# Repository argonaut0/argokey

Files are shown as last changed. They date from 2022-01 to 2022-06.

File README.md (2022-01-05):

# Unnamed Keyboard Project

A Custom 65% Mechanical Keyboard with RGB lighting, an OLED status screen, and volume knob.

Possibly with the first ever keyboard firmware fulling supporting multithreading?

### References

- https://datasheets.raspberrypi.com/rp2040/rp2040-datasheet.pdf
- https://datasheets.raspberrypi.com/rp2040/hardware-design-with-rp2040.pdf

### Symbols and Models
- https://github.com/daprice/keyswitches.pretty
- https://app.ultralibrarian.com/details/718f6c74-6ffb-11eb-9033-0a34d6323d74/Raspberry-Pi/RP2040
- https://app.ultralibrarian.com/details/76A34700-1D87-11E9-AB3A-0A3560A4CCCC/Winbond/W25Q64JVSSIQ

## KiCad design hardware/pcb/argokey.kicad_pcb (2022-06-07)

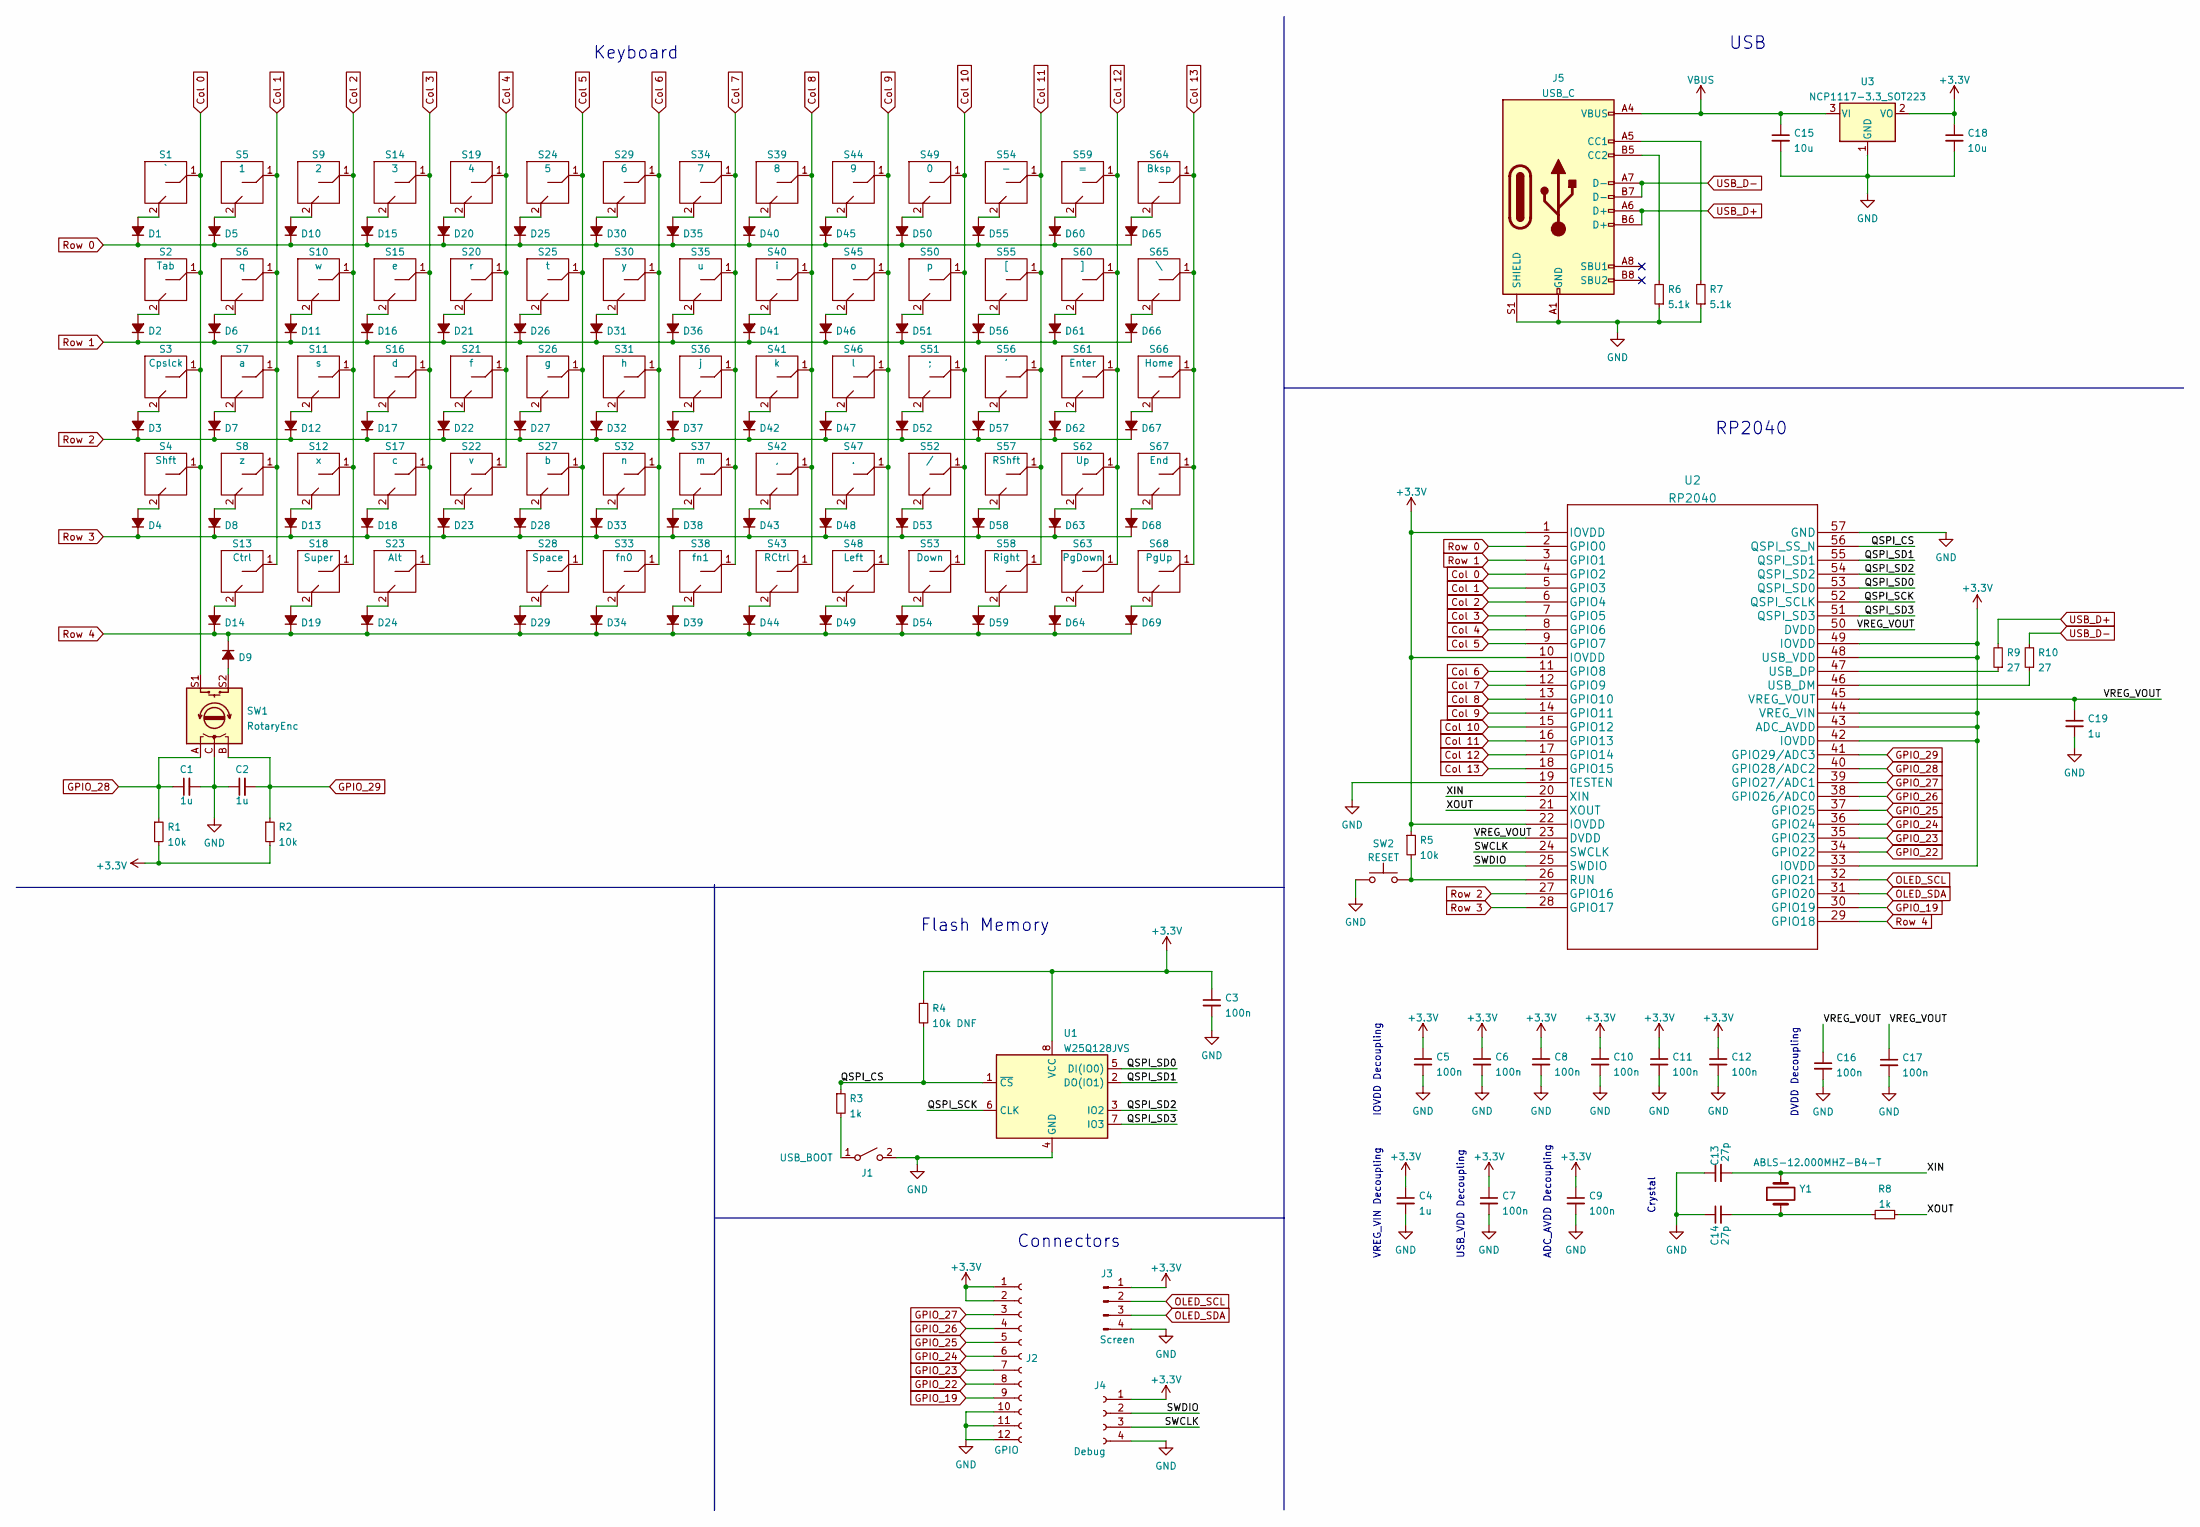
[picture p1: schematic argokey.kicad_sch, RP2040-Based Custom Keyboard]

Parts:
C1, C2, C4, C19: 1u; C_0402_1005Metric_Pad0.74x0.62mm_HandSolder
C3, C5, C6, C7, C8, C9, C10, C11, C12, C16, C17: 100n; C_0402_1005Metric_Pad0.74x0.62mm_HandSolder
C13, C14: 27p; C_0402_1005Metric_Pad0.74x0.62mm_HandSolder
C15, C18: 10u; C_0805_2012Metric_Pad1.18x1.45mm_HandSolder
D1, D2, D3, D4, D5, D6, D7, D8, D9, D10, D11, D12, D13, D14, D15, D16, D18, D19, D20, D21, D22, D23, D24, D25, D26, D27, D28, D29, D30, D31, D32, D33, D34, D35, D36, D37, D38, D39, D40, D41, D42, D43, D44, D45, D46, D47, D48, D49, D50, D51, D52, D53, D54, D55, D56, D57, D58, D59, D60, D61, D62, D63, D64, D65, D66, D67, D68, D69: D_SOD-123
D17: D_SOD-123
J1: USB_BOOT; SW_SPDT_PCM12
J2: GPIO; PinSocket_1x12_P2.54mm_Horizontal
J3: Screen; PinHeader_1x04_P2.54mm_Vertical
J4: Debug; PinSocket_1x04_P2.54mm_Horizontal
J5: USB_C; USB_C_Receptacle_GCT_USB4085
R1, R2, R5: 10k; R_0402_1005Metric_Pad0.72x0.64mm_HandSolder
R3, R8: 1k; R_0402_1005Metric_Pad0.72x0.64mm_HandSolder
R4: 10k DNF; R_0402_1005Metric_Pad0.72x0.64mm_HandSolder
R6, R7: 5.1k; R_0402_1005Metric_Pad0.72x0.64mm_HandSolder
R9, R10: 27; R_0402_1005Metric_Pad0.72x0.64mm_HandSolder
S1: `; SW_Cherry_MX_1.00u_PCB
S2: Tab; SW_Cherry_MX_1.50u_PCB
S3: Cpslck; SW_Cherry_MX_1.75u_PCB
S4: Shft; SW_Cherry_MX_2.25u_PCB
S5: 1; SW_Cherry_MX_1.00u_PCB
S6: q; SW_Cherry_MX_1.00u_PCB
S7: a; SW_Cherry_MX_1.00u_PCB
S8: z; SW_Cherry_MX_1.00u_PCB
S9: 2; SW_Cherry_MX_1.00u_PCB
S10: w; SW_Cherry_MX_1.00u_PCB
S11: s; SW_Cherry_MX_1.00u_PCB
S12: x; SW_Cherry_MX_1.00u_PCB
S13: Ctrl; SW_Cherry_MX_1.25u_PCB
S14: 3; SW_Cherry_MX_1.00u_PCB
S15: e; SW_Cherry_MX_1.00u_PCB
S16: d; SW_Cherry_MX_1.00u_PCB
S17: c; SW_Cherry_MX_1.00u_PCB
S18: Super; SW_Cherry_MX_1.25u_PCB
S19: 4; SW_Cherry_MX_1.00u_PCB
S20: r; SW_Cherry_MX_1.00u_PCB
S21: f; SW_Cherry_MX_1.00u_PCB
S22: v; SW_Cherry_MX_1.00u_PCB
S23: Alt; SW_Cherry_MX_1.25u_PCB
S24: 5; SW_Cherry_MX_1.00u_PCB
S25: t; SW_Cherry_MX_1.00u_PCB
S26: g; SW_Cherry_MX_1.00u_PCB
S27: b; SW_Cherry_MX_1.00u_PCB
S28: Space; SW_Cherry_MX_6.25u_PCB
S29: 6; SW_Cherry_MX_1.00u_PCB
S30: y; SW_Cherry_MX_1.00u_PCB
S31: h; SW_Cherry_MX_1.00u_PCB
S32: n; SW_Cherry_MX_1.00u_PCB
S33: fn0; SW_Cherry_MX_1.00u_PCB
S34: 7; SW_Cherry_MX_1.00u_PCB
S35: u; SW_Cherry_MX_1.00u_PCB
S36: j; SW_Cherry_MX_1.00u_PCB
S37: m; SW_Cherry_MX_1.00u_PCB
S38: fn1; SW_Cherry_MX_1.00u_PCB
S39: 8; SW_Cherry_MX_1.00u_PCB
S40: i; SW_Cherry_MX_1.00u_PCB
S41: k; SW_Cherry_MX_1.00u_PCB
S42: ,; SW_Cherry_MX_1.00u_PCB
S43: RCtrl; SW_Cherry_MX_1.00u_PCB
S44: 9; SW_Cherry_MX_1.00u_PCB
S45: o; SW_Cherry_MX_1.00u_PCB
S46: l; SW_Cherry_MX_1.00u_PCB
S47: .; SW_Cherry_MX_1.00u_PCB
S48: Left; SW_Cherry_MX_1.00u_PCB
S49: 0; SW_Cherry_MX_1.00u_PCB
S50: p; SW_Cherry_MX_1.00u_PCB
S51: ;; SW_Cherry_MX_1.00u_PCB
S52: /; SW_Cherry_MX_1.00u_PCB
S53: Down; SW_Cherry_MX_1.00u_PCB
S54: -; SW_Cherry_MX_1.00u_PCB
S55: [; SW_Cherry_MX_1.00u_PCB
S56: '; SW_Cherry_MX_1.00u_PCB
S57: RShft; SW_Cherry_MX_1.75u_PCB
S58: Right; SW_Cherry_MX_1.00u_PCB
S59: =; SW_Cherry_MX_1.00u_PCB
S60: ]; SW_Cherry_MX_1.00u_PCB
S61: Enter; SW_Cherry_MX_2.25u_PCB
S62: Up; SW_Cherry_MX_1.00u_PCB
S63: PgDown; SW_Cherry_MX_1.00u_PCB
S64: Bksp; SW_Cherry_MX_2.00u_PCB
S65: \; SW_Cherry_MX_1.50u_PCB
S66: Home; SW_Cherry_MX_1.00u_PCB
S67: End; SW_Cherry_MX_1.00u_PCB
S68: PgUp; SW_Cherry_MX_1.00u_PCB
SW1: RotaryEnc; RotaryEncoder_Alps_EC12E-Switch_Vertical_H20mm
SW2: RESET; SW_Tactile_SPST_Angled_PTS645Vx83-2LFS
U1: W25Q128JVS; SOIC-8_5.23x5.23mm_P1.27mm
U2: RP2040; RP2040-QFN-56
U3: NCP1117-3.3_SOT223; SOT-223-3_TabPin2
Y1: ABLS-12.000MHZ-B4-T; Crystal_SMD_HC49-US

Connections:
+3V3: C3.1, C4.1, C5.1, C6.1, C7.1, C8.1, C9.1, C10.1, C11.1, C12.1, C18.1, J2.1, J2.2, J3.1, J4.1, R1.2, R2.2, R4.1, R5.1, U1.8 (VCC), U2.1 (IOVDD), U2.10 (IOVDD), U2.22 (IOVDD), U2.33 (IOVDD), U2.42 (IOVDD), U2.43 (ADC_AVDD), U2.44 (VREG_VIN), U2.48 (USB_VDD), U2.49 (IOVDD), U3.2 (VO)
/QSPI_CS: R3.1, R4.2, U1.1 (~CS), U2.56 (QSPI_SS_N)
/QSPI_SCK: U1.6 (CLK), U2.52 (QSPI_SCLK)
/QSPI_SD0: U1.5 (DI(IO0)), U2.53 (QSPI_SD0)
/QSPI_SD1: U1.2 (DO(IO1)), U2.55 (QSPI_SD1)
/QSPI_SD2: U1.3 (IO2), U2.54 (QSPI_SD2)
/QSPI_SD3: U1.7 (IO3), U2.51 (QSPI_SD3)
/SWCLK: J4.3, U2.24 (SWCLK)
/SWDIO: J4.2, U2.25 (SWDIO)
/VREG_VOUT: C16.1, C17.1, C19.1, U2.23 (DVDD), U2.45 (VREG_VOUT), U2.50 (DVDD)
/XIN: C13.2, U2.20 (XIN), Y1.2
/XOUT: R8.2, U2.21 (XOUT)
Col 0: S1.1, S2.1, S3.1, S4.1, SW1.S1, U2.4 (GPIO2)
Col 1: S5.1, S6.1, S7.1, S8.1, S13.1, U2.5 (GPIO3)
Col 2: S9.1, S10.1, S11.1, S12.1, S18.1, U2.6 (GPIO4)
Col 3: S14.1, S15.1, S16.1, S17.1, S23.1, U2.7 (GPIO5)
Col 4: S19.1, S20.1, S21.1, S22.1, U2.8 (GPIO6)
Col 5: S24.1, S25.1, S26.1, S27.1, S28.1, U2.9 (GPIO7)
Col 6: S29.1, S30.1, S31.1, S32.1, S33.1, U2.11 (GPIO8)
Col 7: S34.1, S35.1, S36.1, S37.1, S38.1, U2.12 (GPIO9)
Col 8: S39.1, S40.1, S41.1, S42.1, S43.1, U2.13 (GPIO10)
Col 9: S44.1, S45.1, S46.1, S47.1, S48.1, U2.14 (GPIO11)
Col 10: S49.1, S50.1, S51.1, S52.1, S53.1, U2.15 (GPIO12)
Col 11: S54.1, S55.1, S56.1, S57.1, S58.1, U2.16 (GPIO13)
Col 12: S59.1, S60.1, S61.1, S62.1, S63.1, U2.17 (GPIO14)
Col 13: S64.1, S65.1, S66.1, S67.1, S68.1, U2.18 (GPIO15)
GND: C1.2, C2.1, C3.2, C4.2, C5.2, C6.2, C7.2, C8.2, C9.2, C10.2, C11.2, C12.2, C13.1, C14.1, C15.2, C16.2, C17.2, C18.2, C19.2, J1.2 (B), J2.10, J2.11, J2.12, J3.4, J4.4, J5.A1 (GND), J5.A12 (GND), J5.B1 (GND), J5.B12 (GND), J5.S1 (SHIELD), R6.1, R7.1, SW1.C, SW2.1, U1.4 (GND), U2.19 (TESTEN), U2.57 (GND), U3.1 (GND)
GPIO_19: J2.9, U2.30 (GPIO19)
GPIO_22: J2.8, U2.34 (GPIO22)
GPIO_23: J2.7, U2.35 (GPIO23)
GPIO_24: J2.6, U2.36 (GPIO24)
GPIO_25: J2.5, U2.37 (GPIO25)
GPIO_26: J2.4, U2.38 (GPIO26/ADC0)
GPIO_27: J2.3, U2.39 (GPIO27/ADC1)
GPIO_28: C1.1, R1.1, SW1.A, U2.40 (GPIO28/ADC2)
GPIO_29: C2.2, R2.1, SW1.B, U2.41 (GPIO29/ADC3)
unnamed: C14.2, R8.1, Y1.1
unnamed: D1.2 (A), S1.2
unnamed: D2.2 (A), S2.2
unnamed: D3.2 (A), S3.2
unnamed: D4.2 (A), S4.2
unnamed: D5.2 (A), S5.2
unnamed: D6.2 (A), S6.2
unnamed: D7.2 (A), S7.2
unnamed: D8.2 (A), S8.2
unnamed: D9.2 (A), SW1.S2
unnamed: D10.2 (A), S9.2
unnamed: D11.2 (A), S10.2
unnamed: D12.2 (A), S11.2
unnamed: D13.2 (A), S12.2
unnamed: D14.2 (A), S13.2
unnamed: D15.2 (A), S14.2
unnamed: D16.2 (A), S15.2
unnamed: D17.2 (A), S16.2
unnamed: D18.2 (A), S17.2
unnamed: D19.2 (A), S18.2
unnamed: D20.2 (A), S19.2
unnamed: D21.2 (A), S20.2
unnamed: D22.2 (A), S21.2
unnamed: D23.2 (A), S22.2
unnamed: D24.2 (A), S23.2
unnamed: D25.2 (A), S24.2
unnamed: D26.2 (A), S25.2
unnamed: D27.2 (A), S26.2
unnamed: D28.2 (A), S27.2
unnamed: D29.2 (A), S28.2
unnamed: D30.2 (A), S29.2
unnamed: D31.2 (A), S30.2
unnamed: D32.2 (A), S31.2
unnamed: D33.2 (A), S32.2
unnamed: D34.2 (A), S33.2
unnamed: D35.2 (A), S34.2
unnamed: D36.2 (A), S35.2
unnamed: D37.2 (A), S36.2
unnamed: D38.2 (A), S37.2
unnamed: D39.2 (A), S38.2
unnamed: D40.2 (A), S39.2
unnamed: D41.2 (A), S40.2
unnamed: D42.2 (A), S41.2
unnamed: D43.2 (A), S42.2
unnamed: D44.2 (A), S43.2
unnamed: D45.2 (A), S44.2
unnamed: D46.2 (A), S45.2
unnamed: D47.2 (A), S46.2
unnamed: D48.2 (A), S47.2
unnamed: D49.2 (A), S48.2
unnamed: D50.2 (A), S49.2
unnamed: D51.2 (A), S50.2
unnamed: D52.2 (A), S51.2
unnamed: D53.2 (A), S52.2
unnamed: D54.2 (A), S53.2
unnamed: D55.2 (A), S54.2
unnamed: D56.2 (A), S55.2
unnamed: D57.2 (A), S56.2
unnamed: D58.2 (A), S57.2
unnamed: D59.2 (A), S58.2
unnamed: D60.2 (A), S59.2
unnamed: D61.2 (A), S60.2
unnamed: D62.2 (A), S61.2
unnamed: D63.2 (A), S62.2
unnamed: D64.2 (A), S63.2
unnamed: D65.2 (A), S64.2
unnamed: D66.2 (A), S65.2
unnamed: D67.2 (A), S66.2
unnamed: D68.2 (A), S67.2
unnamed: D69.2 (A), S68.2
unnamed: J1.1 (A), R3.2
unnamed: J5.A5 (CC1), R7.2
unnamed: J5.B5 (CC2), R6.2
unnamed: R5.2, SW2.2, U2.26 (RUN)
unnamed: R9.1, U2.47 (USB_DP)
unnamed: R10.1, U2.46 (USB_DM)
OLED_SCL: J3.2, U2.32 (GPIO21)
OLED_SDA: J3.3, U2.31 (GPIO20)
Row 0: D1.1 (K), D5.1 (K), D10.1 (K), D15.1 (K), D20.1 (K), D25.1 (K), D30.1 (K), D35.1 (K), D40.1 (K), D45.1 (K), D50.1 (K), D55.1 (K), D60.1 (K), D65.1 (K), U2.2 (GPIO0)
Row 1: D2.1 (K), D6.1 (K), D11.1 (K), D16.1 (K), D21.1 (K), D26.1 (K), D31.1 (K), D36.1 (K), D41.1 (K), D46.1 (K), D51.1 (K), D56.1 (K), D61.1 (K), D66.1 (K), U2.3 (GPIO1)
Row 2: D3.1 (K), D7.1 (K), D12.1 (K), D17.1 (K), D22.1 (K), D27.1 (K), D32.1 (K), D37.1 (K), D42.1 (K), D47.1 (K), D52.1 (K), D57.1 (K), D62.1 (K), D67.1 (K), U2.27 (GPIO16)
Row 3: D4.1 (K), D8.1 (K), D13.1 (K), D18.1 (K), D23.1 (K), D28.1 (K), D33.1 (K), D38.1 (K), D43.1 (K), D48.1 (K), D53.1 (K), D58.1 (K), D63.1 (K), D68.1 (K), U2.28 (GPIO17)
Row 4: D9.1 (K), D14.1 (K), D19.1 (K), D24.1 (K), D29.1 (K), D34.1 (K), D39.1 (K), D44.1 (K), D49.1 (K), D54.1 (K), D59.1 (K), D64.1 (K), D69.1 (K), U2.29 (GPIO18)
USB_D+: J5.A6 (D+), J5.B6 (D+), R9.2
USB_D-: J5.A7 (D-), J5.B7 (D-), R10.2
VBUS: C15.1, J5.A4 (VBUS), J5.A9 (VBUS), J5.B4 (VBUS), J5.B9 (VBUS), U3.3 (VI); also elsewhere on the board

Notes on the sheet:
Keyboard
Flash Memory
USB
Connectors
USB_VDD Decoupling
RP2040
ADC_AVDD Decoupling
IOVDD Decoupling
DVDD Decoupling
VREG_VIN Decoupling
Crystal

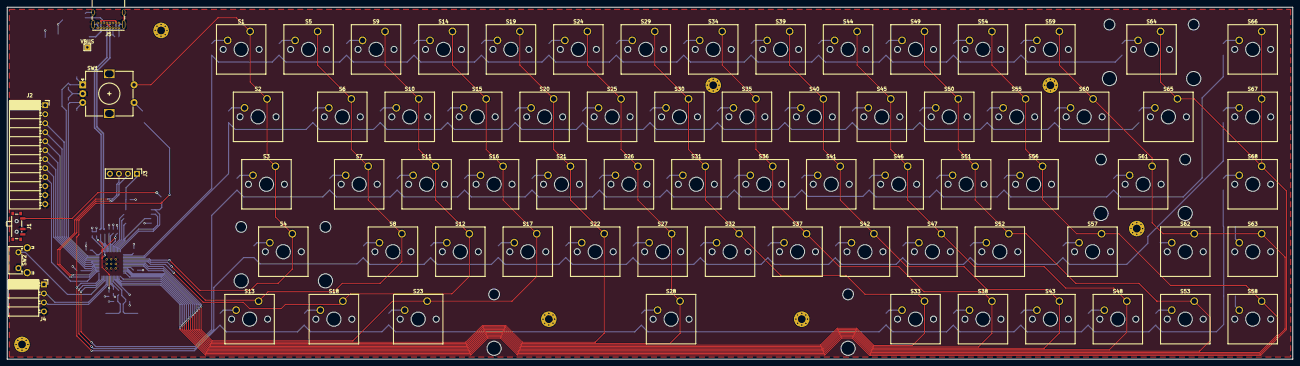
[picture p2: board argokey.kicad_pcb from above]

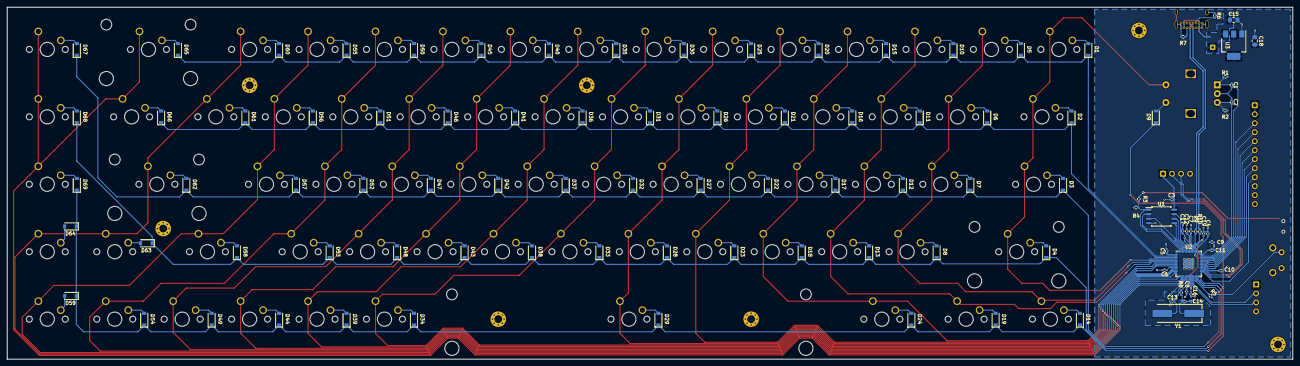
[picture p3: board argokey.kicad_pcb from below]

Board: 2 copper layers, 363.1 x 99.4 mm, 178 parts (102 on the bottom side), 122 nets.

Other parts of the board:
VBUS: TestPoint_THTPad_1.5x1.5mm_Drill0.7mm

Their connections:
VBUS: VBUS.1; also elsewhere on the board

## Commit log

2022-01-05 Remove gitignore files
    [RP2040.kicad_sch, Switches.kicad_sch, argokey.kicad_pcb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]
2022-01-05 Change flash to 16M
    [argokey.kicad_sch]
2022-01-05 Schematic: RP2040 Power
    [argokey.kicad_sch]
2022-01-05 Rev 1 Schematic
    [argokey.kicad_sch]
2022-01-06 Sch: Add connectors
    [argokey.kicad_sch]
2022-01-06 Sch: Replace Flash, Mark Non-con
    [argokey.kicad_sch]
2022-01-06 Sch: Set USB GND VBUS power output
    [argokey.kicad_sch]
2022-01-06 Sch: Update RP2040 symbol pin types
    [argokey.kicad_sch]
2022-01-06 "Sch: Assign most footprints"
    [argokey.kicad_sch]
2022-01-06 Sch: Remove Diode values
    [argokey.kicad_sch]
2022-01-06 PCB: Layout keys/diodes
    [argokey.kicad_pcb]
2022-01-07 PCB: Most traces
    [argokey.kicad_pcb, argokey.kicad_sch]
2022-01-08 PCB: All
    [argokey.kicad_pcb]
2022-01-10 PCB: Fix Errors
    [argokey.kicad_pcb]
2022-04-18 Move all smd on one side
    [argokey.kicad_pcb, argokey.kicad_sch]
2022-04-18 Rev 2 Draft
    [argokey.kicad_pcb]
2022-06-07 First prod rev
    [argokey.kicad_pcb, argokey.kicad_sch]
